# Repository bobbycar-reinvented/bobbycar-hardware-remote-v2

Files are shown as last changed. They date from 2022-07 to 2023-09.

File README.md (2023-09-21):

# bobbycar-hardware-remote-v2

## 3dmodels
3d models are created in Fusion 360. Only exported stl will be available here.

## firmware
This is the main firmware. It is based on other bobbycar firmware (features same gui lib for example).

## kicad
All pcb files are created in KiCad. jlcpcb exports are available, although it is recommended to check the files before ordering.

## Pictures



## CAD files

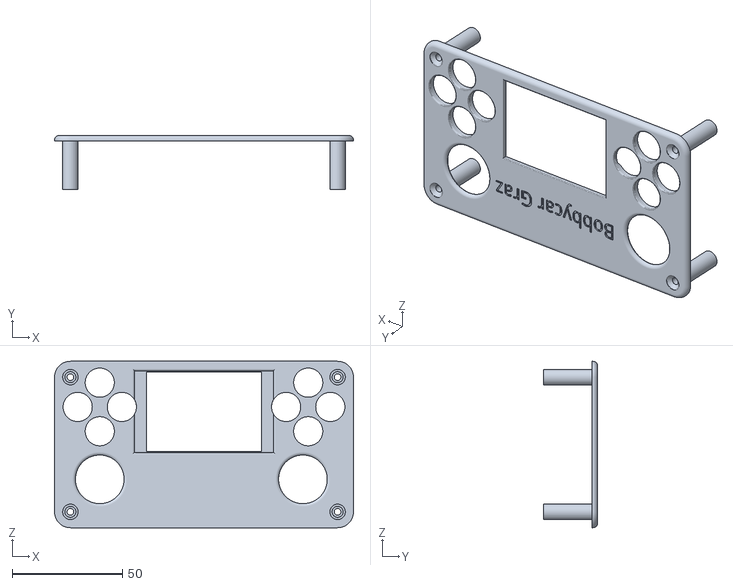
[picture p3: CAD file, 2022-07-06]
3dmodels/Top.stl
135.4 x 24.5 x 75.4

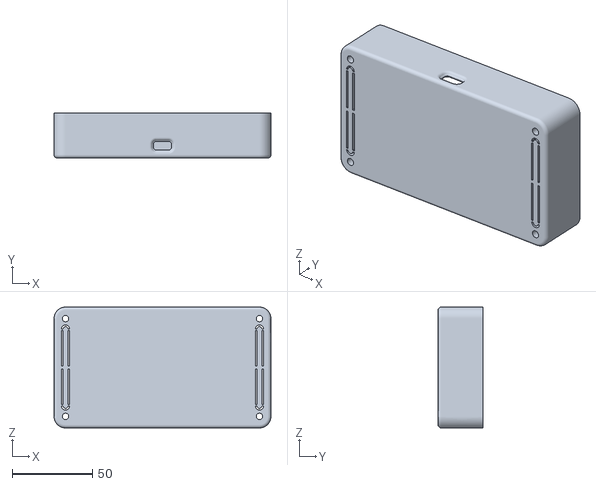
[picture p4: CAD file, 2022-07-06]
3dmodels/Bottom.stl
135.4 x 28.0 x 75.4

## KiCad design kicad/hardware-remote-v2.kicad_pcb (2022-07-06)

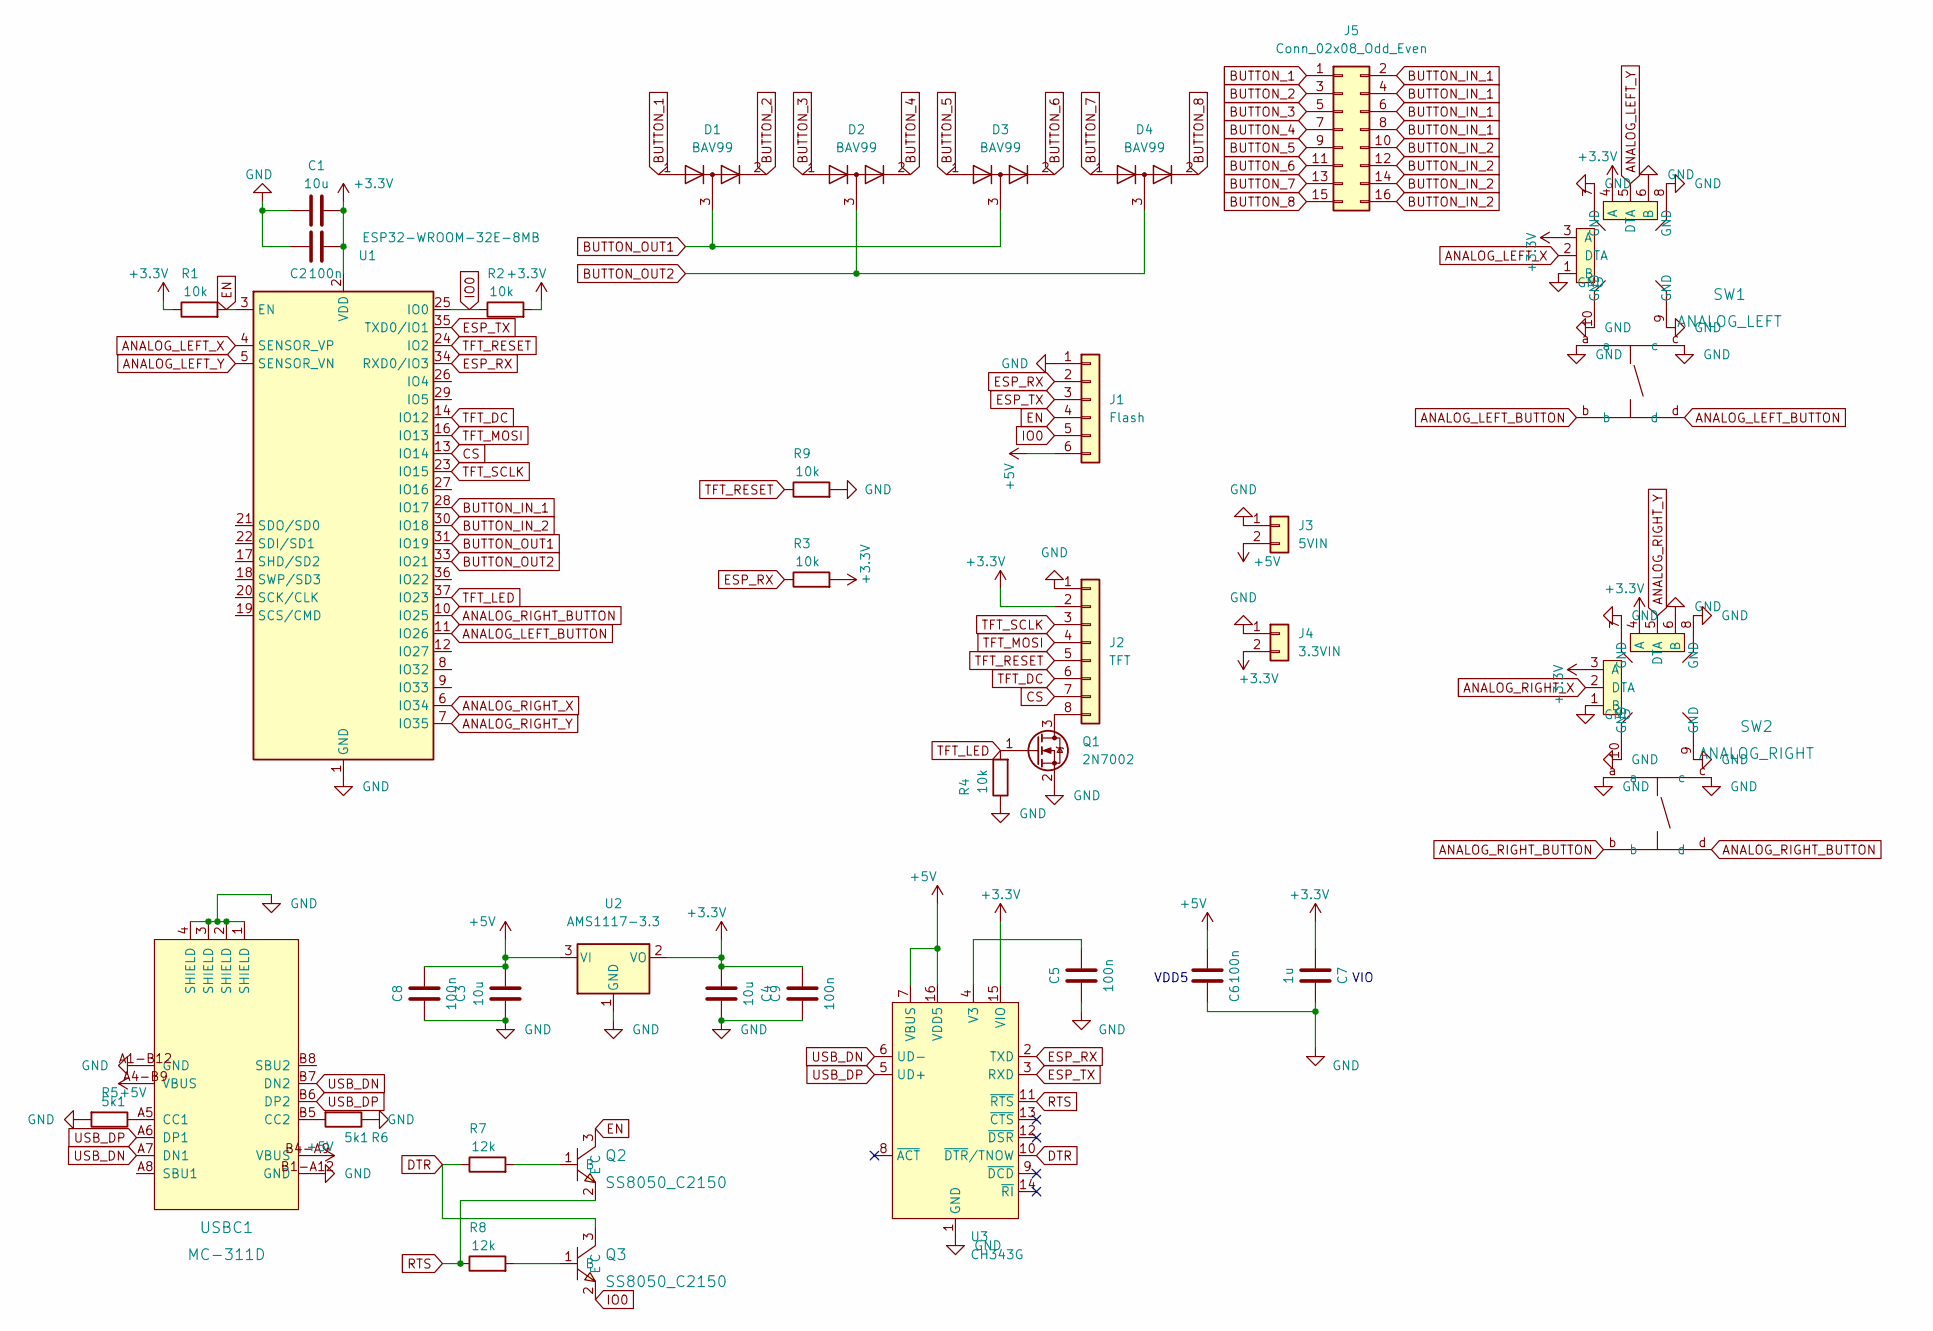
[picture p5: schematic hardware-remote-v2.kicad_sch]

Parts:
C1, C3, C4: 10u; C_0603_1608Metric; LCSC Part # C19702
C2, C5, C6, C8, C9: 100n; C_0603_1608Metric; LCSC Part # C14663
C7: 1u; C_0603_1608Metric; LCSC Part # C15849
D1, D2, D3, D4: BAV99; SOT-23; LCSC C2500
J1: Flash; JST_XH_B6B-XH-A_1x06_P2.50mm_Vertical
J2: TFT; PinSocket_1x08_P2.54mm_Vertical
J3: 5VIN; PinHeader_1x02_P2.54mm_Vertical
J4: 3.3VIN; PinHeader_1x02_P2.54mm_Vertical
J5: Conn_02x08_Odd_Even; PinHeader_2x08_P2.54mm_Vertical
Q1: 2N7002; SOT-23; LCSC C8545
Q2, Q3: SS8050_C2150; SOT-23-3_L2.9-W1.3-P1.90-LS2.4-BR; LCSC Part C2150
R1, R2, R3, R4, R9: 10k; R_0603_1608Metric; LCSC C25804
R5, R6: 5k1; R_0603_1608Metric; LCSC C23186
R7, R8: 12k; R_0603_1608Metric; LCSC C22790
SW1: ANALOG_LEFT; SW-TH_RKJXV122400D; LCSC Part C2687349
SW2: ANALOG_RIGHT; SW-TH_RKJXV122400D; LCSC Part C2687349
U1: ESP32-WROOM-32E-8MB; ESP32-WROOM-32; LCSC C701342
U2: AMS1117-3.3; SOT-223-3_TabPin2; LCSC C6186
U3: CH343G; SOIC-16_3.9x9.9mm_P1.27mm; LCSC C2844153
USBC1: MC-311D; USB-C-SMD_MC-311D; LCSC Part C136423

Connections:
+3V3: C1.2, C2.2, C4.1, C7.2, C9.2, J2.2, J4.2, R1.1, R2.2, R3.2, SW1.3 (A), SW1.4 (A), SW2.3 (A), SW2.4 (A), U1.2 (VDD), U2.2 (VO), U3.15 (VIO)
+5V: C3.2, C6.2, C8.2, J1.6, J3.2, U2.3 (VI), U3.7 (VBUS), U3.16 (VDD5), USBC1.A4-B9 (VBUS), USBC1.B4-A9 (VBUS); also elsewhere on the board
ANALOG_LEFT_BUTTON: SW1.b, SW1.d, U1.11 (IO26)
ANALOG_LEFT_X: SW1.2 (DTA), U1.4 (SENSOR_VP)
ANALOG_LEFT_Y: SW1.5 (DTA), U1.5 (SENSOR_VN)
ANALOG_RIGHT_BUTTON: SW2.b, SW2.d, U1.10 (IO25)
ANALOG_RIGHT_X: SW2.2 (DTA), U1.6 (IO34)
ANALOG_RIGHT_Y: SW2.5 (DTA), U1.7 (IO35)
BUTTON_1: D1.1 (K), J5.1
BUTTON_2: D1.2 (A), J5.3
BUTTON_3: D2.1 (K), J5.5
BUTTON_4: D2.2 (A), J5.7
BUTTON_5: D3.1 (K), J5.9
BUTTON_6: D3.2 (A), J5.11
BUTTON_7: D4.1 (K), J5.13
BUTTON_8: D4.2 (A), J5.15
BUTTON_IN_1: J5.2, J5.4, J5.6, J5.8, U1.28 (IO17)
BUTTON_IN_2: J5.10, J5.12, J5.14, J5.16, U1.30 (IO18)
BUTTON_OUT1: D1.3 (K), D3.3 (K), U1.31 (IO19)
BUTTON_OUT2: D2.3 (K), D4.3 (K), U1.33 (IO21)
CS: J2.7, U1.13 (IO14)
DTR: Q3.3 (C), R7.1, U3.10 (~DTR/TNOW)
EN: J1.4, Q2.3 (C), R1.2, U1.3 (EN); also elsewhere on the board
ESP_RX: J1.2, R3.1, U1.34 (RXD0/IO3), U3.2 (TXD); also elsewhere on the board
ESP_TX: J1.3, U1.35 (TXD0/IO1), U3.3 (RXD); also elsewhere on the board
GND: C1.1, C2.1, C3.1, C4.2, C5.1, C6.1, C7.1, C8.1, C9.1, J1.1, J2.1, J3.1, J4.1, Q1.2 (S), R4.1, R5.2, R6.1, R9.2, SW1.1 (B), SW1.6 (B), SW1.7 (GND), SW1.8 (GND), SW1.9 (GND), SW1.10 (GND), SW1.a, SW1.c, SW2.1 (B), SW2.6 (B), SW2.7 (GND), SW2.8 (GND), SW2.9 (GND), SW2.10 (GND), SW2.a, SW2.c, U1.1 (GND), U1.15 (GND), U1.38 (GND), U1.39 (GND), U2.1 (GND), U3.1 (GND), USBC1.1 (SHIELD), USBC1.2 (SHIELD), USBC1.3 (SHIELD), USBC1.4 (SHIELD), USBC1.A1-B12 (GND), USBC1.B1-A12 (GND); also elsewhere on the board
IO0: J1.5, Q3.2 (E), R2.1, U1.25 (IO0); also elsewhere on the board
unnamed: C5.2, U3.4 (V3)
unnamed: J2.8, Q1.3 (D)
unnamed: Q2.1 (B), R7.2
unnamed: Q3.1 (B), R8.2
unnamed: R5.1, USBC1.A5 (CC1)
unnamed: R6.2, USBC1.B5 (CC2)
RTS: Q2.2 (E), R8.1, U3.11 (~RTS)
TFT_DC: J2.6, U1.14 (IO12)
TFT_LED: Q1.1 (G), R4.2, U1.37 (IO23)
TFT_MOSI: J2.4, U1.16 (IO13)
TFT_RESET: J2.5, R9.1, U1.24 (IO2)
TFT_SCLK: J2.3, U1.23 (IO15)
USB_DN: U3.6 (UD-), USBC1.A7 (DN1), USBC1.B7 (DN2)
USB_DP: U3.5 (UD+), USBC1.A6 (DP1), USBC1.B6 (DP2)

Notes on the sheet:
VDD5
VIO

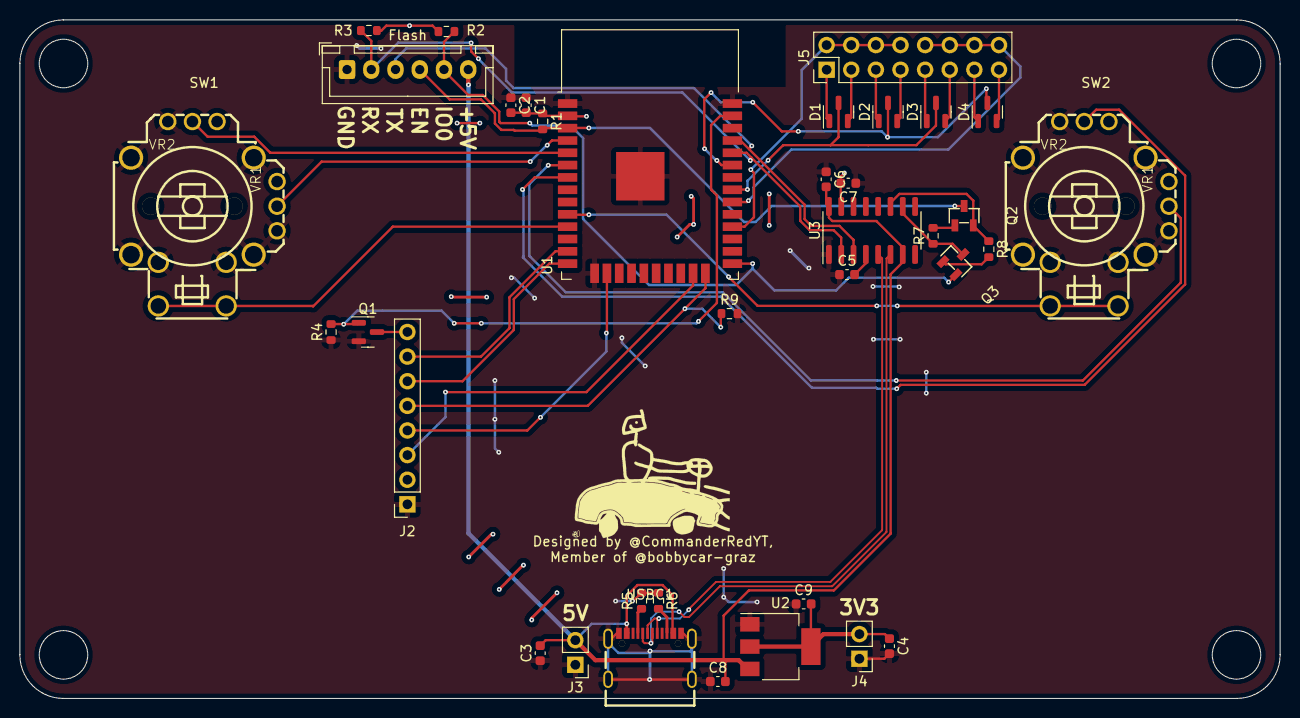
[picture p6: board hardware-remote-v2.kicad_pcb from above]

Board: 2 copper layers, 130.0 x 70.0 mm, 36 parts (0 on the bottom side), 41 nets.

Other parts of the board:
Flash: Flash; JST_XH_B6B-XH-A_1x06_P2.50mm_Vertical

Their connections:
+5V: Flash.6; also elsewhere on the board
EN: Flash.4; also elsewhere on the board
ESP_RX: Flash.2; also elsewhere on the board
ESP_TX: Flash.3; also elsewhere on the board
GND: Flash.1; also elsewhere on the board
IO0: Flash.5; also elsewhere on the board

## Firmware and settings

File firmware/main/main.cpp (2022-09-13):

constexpr const char * const TAG = "BOBBY_REMOTE";

// esp-idf includes
#include <esp32-hal-gpio.h>
#include <esp_log.h>
#include <esp_pm.h>
#include <esp_system.h>

// 3rdparty lib includes
#include <espchrono.h>
#include <screenmanager.h>

// local includes
#include "analog_sticks.h"
#include "ble.h"
#include "dualboot.h"
#include "screens.h"
#include "screens/buttonmapscreen.h"
#include "screens/calibrateanalogsticksscreen.h"
#include "screens/statusscreen.h"
#include "settings.h"
#include "taskmanager.h"

using namespace std::chrono_literals;

extern "C" void app_main()
{
    esp_reset_reason_t reset_reason = esp_reset_reason();
    if (reset_reason != ESP_RST_SW) {
        boot_gamecontroller = false;
    }

    pinMode(PIN_LED_BACKLIGHT, OUTPUT);
    digitalWrite(PIN_LED_BACKLIGHT, LOW);

    display::init();

    bootLabel.redraw("settings");

    if (const auto result = configs.init("bobbyremote"); result != ESP_OK)
        ESP_LOGE(TAG, "config_init_settings() failed with %s", esp_err_to_name(result));

    bootLabel.redraw("analog_sticks");

    analog_sticks::read_buttons();

    for (const auto &task : schedulerTasks)
    {
        ESP_LOGI(TAG, "Init task %s", task.name());
        bootLabel.redraw(task.name());
        task.setup();
    }

    // check if analog sticks are mapped
    if (
        configs.dpadUp.value() == INPUT_MAPPING_NONE ||
        configs.dpadDown.value() == INPUT_MAPPING_NONE ||
        configs.dpadLeft.value() == INPUT_MAPPING_NONE ||
        configs.dpadRight.value() == INPUT_MAPPING_NONE ||
        configs.dpadUp2.value() == INPUT_MAPPING_NONE ||
        configs.dpadDown2.value() == INPUT_MAPPING_NONE ||
        configs.dpadLeft2.value() == INPUT_MAPPING_NONE ||
        configs.dpadRight2.value() == INPUT_MAPPING_NONE
       )
    {
        espgui::switchScreen<ButtonMapScreen>();
        ble::disableAutoConnect();
    }
    else if (analog_sticks::needs_calibration() || analog_sticks::both_buttons_pressed())
    {
        espgui::switchScreen<CalibrateAnalogStickScreen>(true);
        ble::disableAutoConnect();
    }
    else if (!boot_gamecontroller)
    {
        espgui::switchScreen<StatusScreen>();
    }
    else
    {
        ESP_LOGI(TAG, "Booting into gamecontroller");
    }

    while (true)
    {
        const auto now = espchrono::millis_clock::now();

        for (auto &schedulerTask : schedulerTasks)
        {
            schedulerTask.loop();
        }

        display::update();

        vTaskDelay(1);
    }
}

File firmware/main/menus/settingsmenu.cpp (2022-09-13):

#include "settingsmenu.h"

// 3rdparty lib includes
#include <actions/popscreenaction.h>
#include <actions/pushscreenaction.h>
#include <menuitem.h>
#include <screenmanager.h>
#include <textwithvaluehelper.h>

// local includes
#include "accessors/settingsaccessors.h"
#include "bobbychangevaluedisplay.h"
#include "bobbycheckbox.h"
#include "icons/bluetooth.h"
#include "menus/blesettingsmenu.h"
#include "typesafeenumchangemenu.h"

namespace {
constexpr char TEXT_DEADBAND[] = "Deadband";
constexpr char TEXT_INVERTLEFTX[] = "Invert left X";
constexpr char TEXT_INVERTLEFTY[] = "Invert left Y";
constexpr char TEXT_INVERTRIGHTX[] = "Invert right X";
constexpr char TEXT_INVERTRIGHTY[] = "Invert right Y";
constexpr char TEXT_ANALOG_STICK_MODE[] = "Analog stick mode";
constexpr char TEXT_BLE_SETTINGS[] = "BLE Settings";

constexpr char TEXT_FRONT_STEER[] = "Front Steer Pwm";
constexpr char TEXT_BACK_STEER[] = "Back Steer Pwm";
constexpr char TEXT_FRONT_DRIVE[] = "Front Drive Pwm";
constexpr char TEXT_BACK_DRIVE[] = "Back Drive Pwm";

constexpr char TEXT_GAMECONTROLLER_BACKLIGHT[] = "Gamecontroller backlight";

using namespace espgui;

using DeadbandChangeScreen = espgui::makeComponent<
    BobbyChangeValueDisplay<uint16_t>,
    espgui::StaticText<TEXT_DEADBAND>,
    DeadBandAccessor,
    espgui::ConfirmActionInterface<espgui::PopScreenAction>,
    espgui::BackActionInterface<espgui::PopScreenAction>
>;

using FrontSteerChangeMenu = espgui::makeComponent<
        BobbyChangeValueDisplay<int16_t>,
        espgui::StaticText<TEXT_FRONT_STEER>,
        FrontSteerAccessor,
        espgui::ConfirmActionInterface<espgui::PopScreenAction>,
        espgui::BackActionInterface<espgui::PopScreenAction>
>;

using BackSteerChangeMenu = espgui::makeComponent<
        BobbyChangeValueDisplay<int16_t>,
        espgui::StaticText<TEXT_BACK_STEER>,
        BackSteerAccessor,
        espgui::ConfirmActionInterface<espgui::PopScreenAction>,
        espgui::BackActionInterface<espgui::PopScreenAction>
>;

using FrontDriveChangeMenu = espgui::makeComponent<
        BobbyChangeValueDisplay<int16_t>,
        espgui::StaticText<TEXT_FRONT_DRIVE>,
        FrontDriveAccessor,
        espgui::ConfirmActionInterface<espgui::PopScreenAction>,
        espgui::BackActionInterface<espgui::PopScreenAction>
>;

using BackDriveChangeMenu = espgui::makeComponent<
        BobbyChangeValueDisplay<int16_t>,
        espgui::StaticText<TEXT_BACK_DRIVE>,
        BackDriveAccessor,
        espgui::ConfirmActionInterface<espgui::PopScreenAction>,
        espgui::BackActionInterface<espgui::PopScreenAction>
>;
} // namespace

SettingsMenu::SettingsMenu()
{
    using namespace espgui;

    constructMenuItem<makeComponent<MenuItem, TextWithHighlightedValueHelper<TEXT_DEADBAND, DeadBandAccessor>, PushScreenAction<DeadbandChangeScreen>>>();

    constructMenuItem<makeComponent<MenuItem, StaticText<TEXT_INVERTLEFTX>, BobbyCheckbox, InvertLeftXAccessor>>();
    constructMenuItem<makeComponent<MenuItem, StaticText<TEXT_INVERTLEFTY>, BobbyCheckbox, InvertLeftYAccessor>>();
    constructMenuItem<makeComponent<MenuItem, StaticText<TEXT_INVERTRIGHTX>, BobbyCheckbox, InvertRightXAccessor>>();
    constructMenuItem<makeComponent<MenuItem, StaticText<TEXT_INVERTRIGHTY>, BobbyCheckbox, InvertRightYAccessor>>();

    constructMenuItem<PushScreenTypeSafeChangeMenuItem<AnalogStickMode, TEXT_ANALOG_STICK_MODE>>(&configs.analogStickMode);

    constructMenuItem<makeComponent<MenuItem, TextWithHighlightedValueHelper<TEXT_FRONT_STEER, FrontSteerAccessor>, PushScreenAction<FrontSteerChangeMenu>>>();
    constructMenuItem<makeComponent<MenuItem, TextWithHighlightedValueHelper<TEXT_BACK_STEER, BackSteerAccessor>, PushScreenAction<BackSteerChangeMenu>>>();
    constructMenuItem<makeComponent<MenuItem, TextWithHighlightedValueHelper<TEXT_FRONT_DRIVE, FrontDriveAccessor>, PushScreenAction<FrontDriveChangeMenu>>>();
    constructMenuItem<makeComponent<MenuItem, TextWithHighlightedValueHelper<TEXT_BACK_DRIVE, BackDriveAccessor>, PushScreenAction<BackDriveChangeMenu>>>();

    constructMenuItem<makeComponent<MenuItem, StaticText<TEXT_BLE_SETTINGS>, PushScreenAction<BleSettingsMenu>, StaticMenuItemIcon<&bobbyicons::bluetooth>>>();
    constructMenuItem<makeComponent<MenuItem, StaticText<TEXT_GAMECONTROLLER_BACKLIGHT>, BobbyCheckbox, GamecontrollerBacklightAccessor>>();
}

std::string SettingsMenu::text() const
{
    return "Settings";
}

void SettingsMenu::back()
{
    espgui::popScreen();
}

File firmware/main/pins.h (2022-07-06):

#pragma once

namespace analog_sticks::pins {
constexpr auto left_x = PIN_ANALOG_LEFT_X;
constexpr auto left_y = PIN_ANALOG_LEFT_Y;
constexpr auto left_btn = PIN_ANALOG_LEFT_BTN;

constexpr auto right_x = PIN_ANALOG_RIGHT_X;
constexpr auto right_y = PIN_ANALOG_RIGHT_Y;
constexpr auto right_btn = PIN_ANALOG_RIGHT_BTN;
} // namespace analog_sticks::pins

namespace buttons::pins {
constexpr auto OUT1 = PIN_BTN_OUT1;
constexpr auto OUT2 = PIN_BTN_OUT2;
constexpr auto IN1 = PIN_BTN_IN1;
constexpr auto IN2 = PIN_BTN_IN2;
} // namespace buttons::pins

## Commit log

2022-05-16 Added PCB
    [hardware-remote-v2.kicad_pcb, hardware-remote-v2.kicad_sch]
2022-05-16 Updated usb, still needs someone to put flasher on there
    [hardware-remote-v2.kicad_pcb, hardware-remote-v2.kicad_sch]
2022-05-19 PCB Version Beta 0.1
    [hardware-remote-v2-CuBottom.gbr, hardware-remote-v2-CuTop.gbr, hardware-remote-v2-EdgeCuts.gbr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]
2022-05-19 Fixed DRC
    [hardware-remote-v2.kicad_pcb]
2022-05-19 Exported new production files
    [hardware-remote-v2-CuBottom.gbr, hardware-remote-v2-CuTop.gbr, hardware-remote-v2-EdgeCuts.gbr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]
2022-05-19 Actually use usb c that they can solder
    [hardware-remote-v2-CuBottom.gbr, hardware-remote-v2-CuTop.gbr, hardware-remote-v2-EdgeCuts.gbr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]
2022-05-20 Should be final design, but jlcpcbs rotation is weird
    [hardware-remote-v2-CuBottom.gbr, hardware-remote-v2-CuTop.gbr, hardware-remote-v2-EdgeCuts.gbr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]
2022-05-20 Production files
    [hardware-remote-v2-CuBottom.gbr, hardware-remote-v2-CuTop.gbr, hardware-remote-v2-EdgeCuts.gbr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]
2022-07-06 Added 3d models
    [Bottom.stl, Top.stl]
2022-07-06 Updated / fixed pcb
    [hardware-remote-v2.kicad_pcb, hardware-remote-v2.kicad_sch]
2022-07-06 Basic files for chip config
    [partition_table.csv]
2022-07-06 Added buttons
2022-09-13 Added button logging
